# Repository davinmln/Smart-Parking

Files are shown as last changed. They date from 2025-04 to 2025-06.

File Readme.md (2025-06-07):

# 🛜 SMART PARKING
<p align="center">
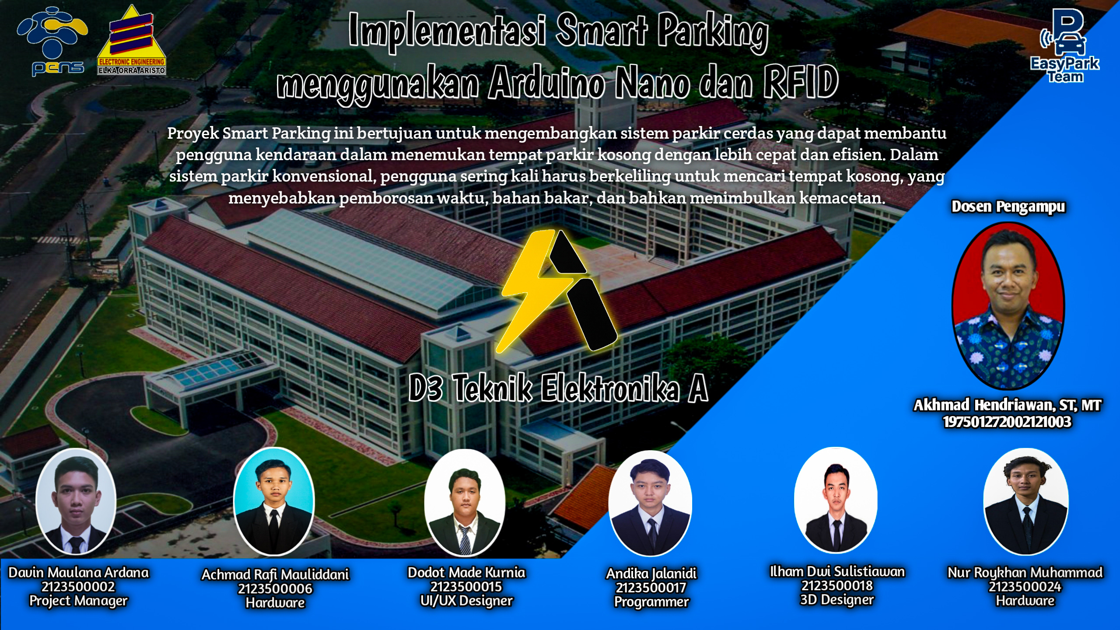
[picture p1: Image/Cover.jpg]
   
</p>

## Support By :
- Dosen Pengampu : Akhmad Hendriawan ST, MT
- Mata Kuliah : Workshop Mikrokontroller
- Program Studi : D3 Teknik Elektronika
- Institusi : Politeknik Elektronika Negeri Surabaya ( PENS )
  
## 👥 EasyPark Team Member
<p align="center">
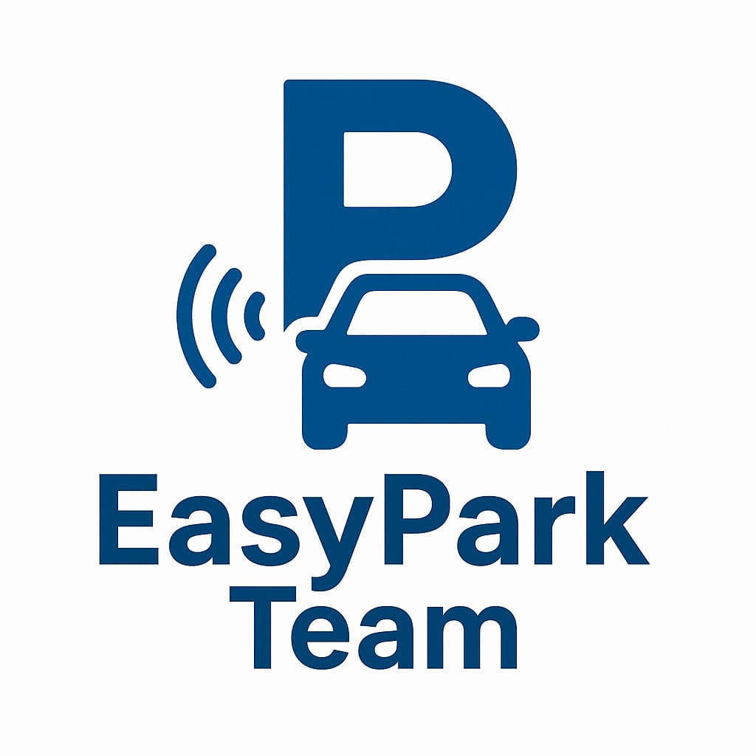
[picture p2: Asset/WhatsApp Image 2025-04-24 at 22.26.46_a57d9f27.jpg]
  
</p>

| Nama | Nrp | Jobdesk |
|:---:|:---:|:---:|
| Davin Maulana Ardana  | 2123500002 | Project Manager |
| Achmad Rafi Mauliddani  | 2123500006 | Hardware |
| Dodot Made Kurnia  | 2123500015 | UI/UX Designer |
| Andika Jalanidi  | 2123500017 | Programmer |
| Ilham Dwi Sulistiawan  | 2123500018 | 3D Designer |
| Nur Roykhan Muhammad | 2123500024 | Hardware |

## Deskripsi Projek
Sistem Smart Parking adalah solusi berbasis teknologi untuk mempermudah pencarian tempat parkir di area umum, seperti apartemen, pusat perbelanjaan, dan area publik lainnya. Sistem ini menggunakan sensor dan teknologi IoT untuk mendeteksi ketersediaan parkir secara real-time dan memberikan informasi langsung kepada pengguna. Tujuan utama proyek ini adalah untuk mengurangi waktu yang dihabiskan pengemudi dalam mencari tempat parkir dan mengoptimalkan penggunaan lahan parkir yang ada. Sistem ini tidak hanya memberikan kenyamanan bagi pengguna dengan cara yang efisien dan cepat, tetapi juga membantu pengelola parkir dalam memonitor kapasitas dan pendapatan parkir secara otomatis.

## Tujuan Proyek
- Menyediakan solusi parkir yang efisien dan modern untuk mengurangi waktu pencarian tempat parkir oleh pengguna.
- Mengurangi kemacetan di area parkir akibat kendaraan yang berkeliling mencari slot kosong.
- Memberikan informasi ketersediaan tempat parkir secara akurat kepada pengguna.
  
## Komponen 
| Nama Komponen | Kegunaan |
|:---:|:---:|
| Limit Swich | Untuk mengetahui di bagian mana slot parkir yang kosong |
| Infrared Sensor | Untuk mendeteksi apakah mobil sudah melewati pintu parkir |
| RFID  | Sebagai akses keluar dan masuk kendaraan | 
| Servo  | Untuk membuka dan menutup pintu masuk | 
| Arduino Uno  | Sebagai mikrokontroler yang akam di gunakan |
| Lcd Dislay 16x2 | Untuk menampilkan slot kosong di parkiran di pintu masuk |

## Blok Diagram Sistem
<p align="center">
   Foto Tim EasyPark
</p>

## Design PCB
<p align="center">
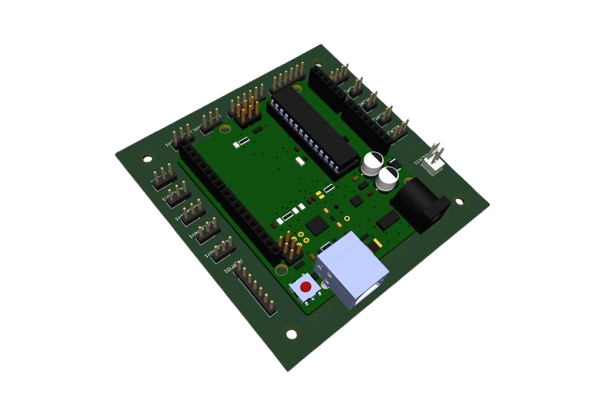
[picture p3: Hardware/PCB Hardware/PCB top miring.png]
   
</p>

## 3D Design Parking Slot
<p align="center">
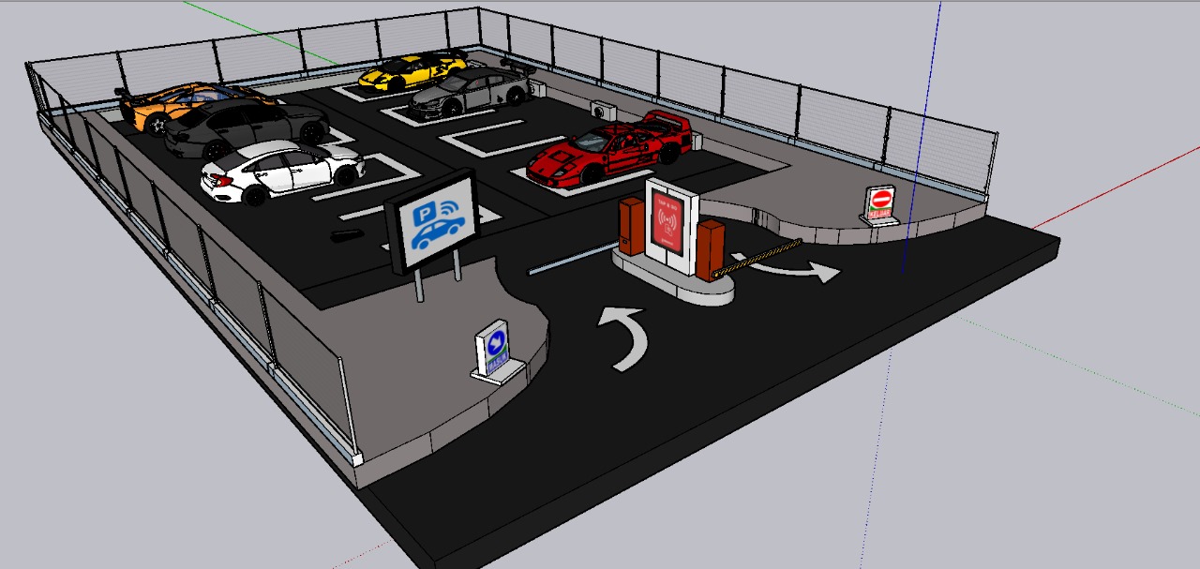
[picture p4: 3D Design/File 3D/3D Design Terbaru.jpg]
   
</p>

## Link Thingiverse 3D Design

**🔗[Teruskan ke website Thingverse](https://www.thingiverse.com/thing:7059087)**

## UI/UX Design
<p align="center">
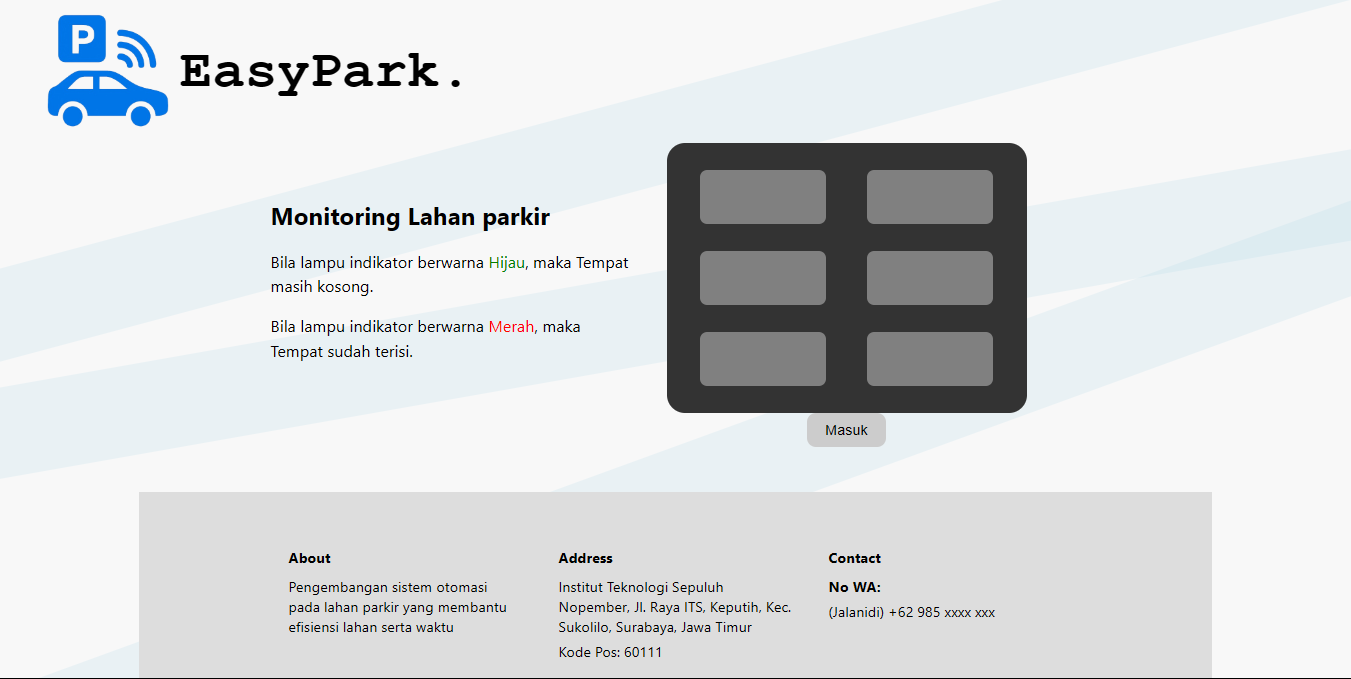
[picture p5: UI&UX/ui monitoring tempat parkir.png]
Foto ui EasyPark
  
</p>

## Simulasi Wokwi
<p align="center">
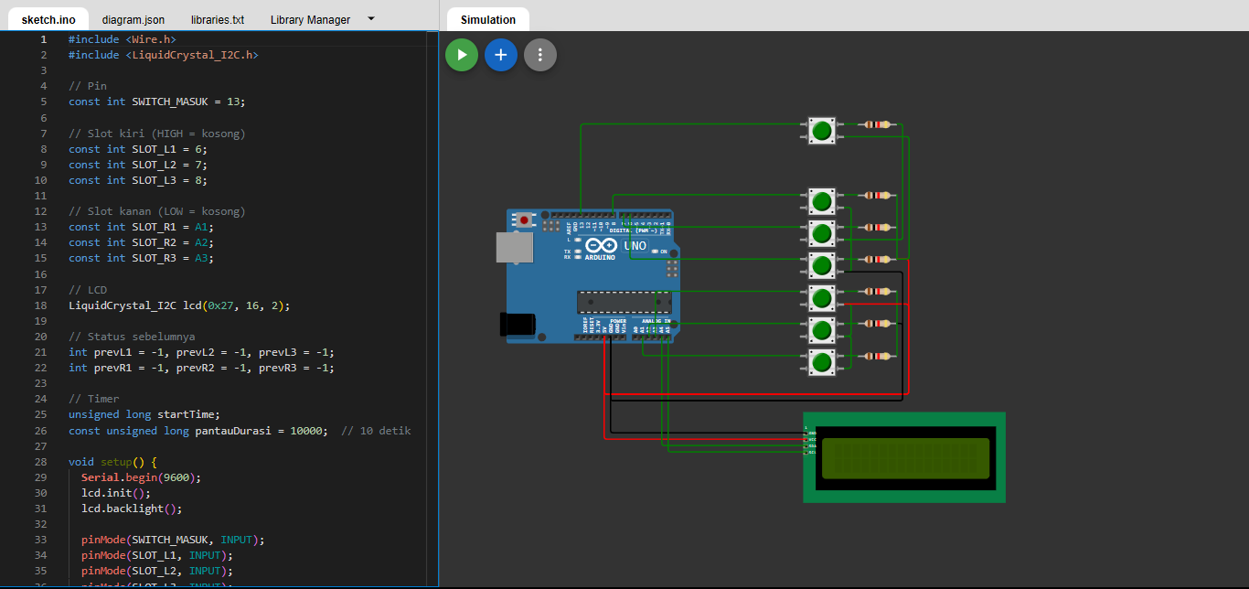
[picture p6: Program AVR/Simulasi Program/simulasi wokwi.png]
Foto simulasi wokwi
  
</p>

## Link Simulasi Wokwi
**🔗[Teruskan ke website Wokwi](https://wokwi.com/projects/433106752911339521)**

## Video Iklan
https://github.com/user-attachments/assets/c66144eb-d369-47d5-b7e9-3379c96ada36

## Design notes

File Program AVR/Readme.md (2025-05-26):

#include <SPI.h>
#include <MFRC522.h>
#include <Servo.h>
#include <Wire.h>
#include <LiquidCrystal_I2C.h>

// RFID
#define SS_PIN 9
#define RST_PIN 10
MFRC522 mfrc522(SS_PIN, RST_PIN);
byte allowedUID[4] = {0x73, 0xDF, 0x91, 0xE2}; // Ganti sesuai UID kartu Anda

// Servo
Servo servoMasuk;
Servo servoKeluar;
const int SERVO_MASUK_PIN = 3;
const int SERVO_KELUAR_PIN = 5;

// Sensor & tombol
const int SENSOR_IR_MASUK = 2;
const int SENSOR_IR_KELUAR = 4;
const int SWITCH_KELUAR = A0;

// Slot kiri (HIGH = kosong)
const int SLOT_L1 = 6;
const int SLOT_L2 = 7;
const int SLOT_L3 = 8;

// Slot kanan (LOW = kosong)
const int SLOT_R1 = A1;
const int SLOT_R2 = A2;
const int SLOT_R3 = A3;

// LCD
LiquidCrystal_I2C lcd(0x27, 16, 2);

// Timer kirim status slot
unsigned long lastSendTime = 0;
const unsigned long interval = 1000;  // 1 detik

// Variabel status slot sebelumnya
int prevL1 = -1, prevL2 = -1, prevL3 = -1;
int prevR1 = -1, prevR2 = -1, prevR3 = -1;

void setup() {
  Serial.begin(9600);
  SPI.begin();
  mfrc522.PCD_Init();

  lcd.init();
  lcd.backlight();
  tampilkanSiapScan();

  servoMasuk.attach(SERVO_MASUK_PIN);
  servoKeluar.attach(SERVO_KELUAR_PIN);
  servoMasuk.write(0);
  servoKeluar.write(0);

  pinMode(SENSOR_IR_MASUK, INPUT);
  pinMode(SENSOR_IR_KELUAR, INPUT);
  pinMode(SWITCH_KELUAR, INPUT);

  pinMode(SLOT_L1, INPUT);
  pinMode(SLOT_L2, INPUT);
  pinMode(SLOT_L3, INPUT);
  pinMode(SLOT_R1, INPUT);
  pinMode(SLOT_R2, INPUT);
  pinMode(SLOT_R3, INPUT);
}

void loop() {
  if (millis() - lastSendTime >= interval) {
    kirimStatusSlot();
    lastSendTime = millis();
  }

  // MODE KELUAR
  if (digitalRead(SWITCH_KELUAR) == LOW) {
    lcd.clear();
    lcd.setCursor(2, 0); lcd.print("Akses Keluar");
    lcd.setCursor(0, 1); lcd.print("Tab Access Card");

    while (digitalRead(SWITCH_KELUAR) == LOW) {
      if (millis() - lastSendTime >= interval) {
        kirimStatusSlot();
        lastSendTime = millis();
      }

      if (mfrc522.PICC_IsNewCardPresent() && mfrc522.PICC_ReadCardSerial()) {
        if (isAllowedUID(mfrc522.uid.uidByte)) {
          mfrc522.PICC_HaltA();
          tampilkanSelamatJalan();
          prosesKeluar();
          break;
        } else {
          lcd.clear();
          lcd.setCursor(3, 0); lcd.print("Kartu Tidak");
          lcd.setCursor(2, 1); lcd.print("Dikenal");
          delayLCD(1000);
          lcd.setCursor(2, 0); lcd.print("Akses Keluar");
          lcd.setCursor(0, 1); lcd.print("Tab Access Card");
        }
      }
    }

    if (digitalRead(SWITCH_KELUAR) == HIGH) {
      tampilkanSiapScan();
    }
    return;
  }

  // Mode masuk - hanya via RFID
  if (!mfrc522.PICC_IsNewCardPresent() || !mfrc522.PICC_ReadCardSerial()) return;

  if (isAllowedUID(mfrc522.uid.uidByte)) {
    bukaPintuMasuk();
    tampilkanSlotKosong();
    tungguKendaraanMasuk();
    tutupPintuMasuk();
  } else {
    lcd.clear();
    lcd.setCursor(0, 0); lcd.print("Akses Ditolak");
    lcd.setCursor(0, 1); lcd.print("Coba lagi");
    delayLCD(1000);
  }

  mfrc522.PICC_HaltA();
  tampilkanSiapScan();
}

// --- Fungsi Cek UID ---
bool isAllowedUID(byte *uid) {
  for (byte i = 0; i < 4; i++) {
    if (uid[i] != allowedUID[i]) return false;
  }
  return true;
}

// --- Tampilkan LCD ---
void tampilkanSiapScan() {
  lcd.clear();
  lcd.setCursor(1, 0); lcd.print("SMART PARKING");
  lcd.setCursor(0, 1); lcd.print("Tab Access Card");
}

void tampilkanSlotKosong() {
  bool L1 = digitalRead(SLOT_L1) == HIGH;
  bool L2 = digitalRead(SLOT_L2) == HIGH;
  bool L3 = digitalRead(SLOT_L3) == HIGH;
  bool R1 = digitalRead(SLOT_R1) == LOW;
  bool R2 = digitalRead(SLOT_R2) == LOW;
  bool R3 = digitalRead(SLOT_R3) == LOW;

  lcd.clear();
  lcd.setCursor(2, 0);
  lcd.print("L:");
  lcd.print(R1 ? "1" : "X");
  lcd.print(R2 ? "2" : "X");
  lcd.print(R3 ? "3" : "X");
  lcd.print(" R:");
  lcd.print(L1 ? "1" : "X");
  lcd.print(L2 ? "2" : "X");
  lcd.print(L3 ? "3" : "X");

  lcd.setCursor(1, 1); lcd.print("Silakan Masuk");
  delayLCD(1000);
}

void tampilkanSelamatJalan() {
  lcd.clear();
  lcd.setCursor(1, 0); lcd.print("Selamat Jalan");
  lcd.setCursor(3, 1); lcd.print("Hati-hati");
  delayLCD(1000);
}

// --- Kontrol Pintu ---
void bukaPintuMasuk() {
  servoMasuk.write(90);
}
void tutupPintuMasuk() {
  servoMasuk.write(0);
}
void tungguKendaraanMasuk() {
  while (digitalRead(SENSOR_IR_MASUK) == HIGH) {
    delay(10);
    kirimStatusSlot();
  }
  lcd.setCursor(0, 1); lcd.print("Kendaraan Masuk");
  while (digitalRead(SENSOR_IR_MASUK) == LOW) {
    delay(10);
    kirimStatusSlot();
  }
}

void prosesKeluar() {
  bukaPintuKeluar();
  tungguKendaraanKeluar();
  tutupPintuKeluar();
  tampilkanSiapScan();
}
void bukaPintuKeluar() {
  servoKeluar.write(90);
}
void tutupPintuKeluar() {
  servoKeluar.write(0);
}
void tungguKendaraanKeluar() {
  while (digitalRead(SENSOR_IR_KELUAR) == HIGH) {
    delay(10);
    kirimStatusSlot();
  }
  lcd.setCursor(0, 1); lcd.print("Kendaraan Keluar");
  while (digitalRead(SENSOR_IR_KELUAR) == LOW) {
    delay(10);
    kirimStatusSlot();
  }
}

// --- Delay non-blokir untuk LCD + Serial ---
void delayLCD(unsigned long durasi) {
  unsigned long start = millis();
  while (millis() - start < durasi) {
    if (millis() - lastSendTime >= interval) {
      kirimStatusSlot();
      lastSendTime = millis();
    }
  }
}

// --- Kirim Status Slot ke Serial dalam Format JSON ---
void kirimStatusSlot() {
  int L1 = digitalRead(SLOT_L1) == LOW ? 1 : 0;
  int L2 = digitalRead(SLOT_L2) == LOW ? 1 : 0;
  int L3 = digitalRead(SLOT_L3) == LOW ? 1 : 0;
  int R1 = digitalRead(SLOT_R1) != LOW;
  int R2 = digitalRead(SLOT_R2) != LOW;
  int R3 = digitalRead(SLOT_R3) != LOW;

  // Kirim hanya jika berubah atau dipanggil periodik
  if (L1 != prevL1 || L2 != prevL2 || L3 != prevL3 ||
      R1 != prevR1 || R2 != prevR2 || R3 != prevR3) {

    Serial.print("{\"L1\":"); Serial.print(L1);
    Serial.print(",\"L2\":"); Serial.print(L2);
    Serial.print(",\"L3\":"); Serial.print(L3);
    Serial.print(",\"R1\":"); Serial.print(R1);
    Serial.print(",\"R2\":"); Serial.print(R2);
    Serial.print(",\"R3\":"); Serial.print(R3);
    Serial.println("}");

    prevL1 = L1; prevL2 = L2; prevL3 = L3;
    prevR1 = R1; prevR2 = R2; prevR3 = R3;
  }
}

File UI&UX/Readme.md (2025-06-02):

# *Tampilan design UI monitoring tempat parkir*

<p align="center">
  Foto ui EasyPark
</p>

# *Tampilan design UI Pada Figma*
<p align="center">
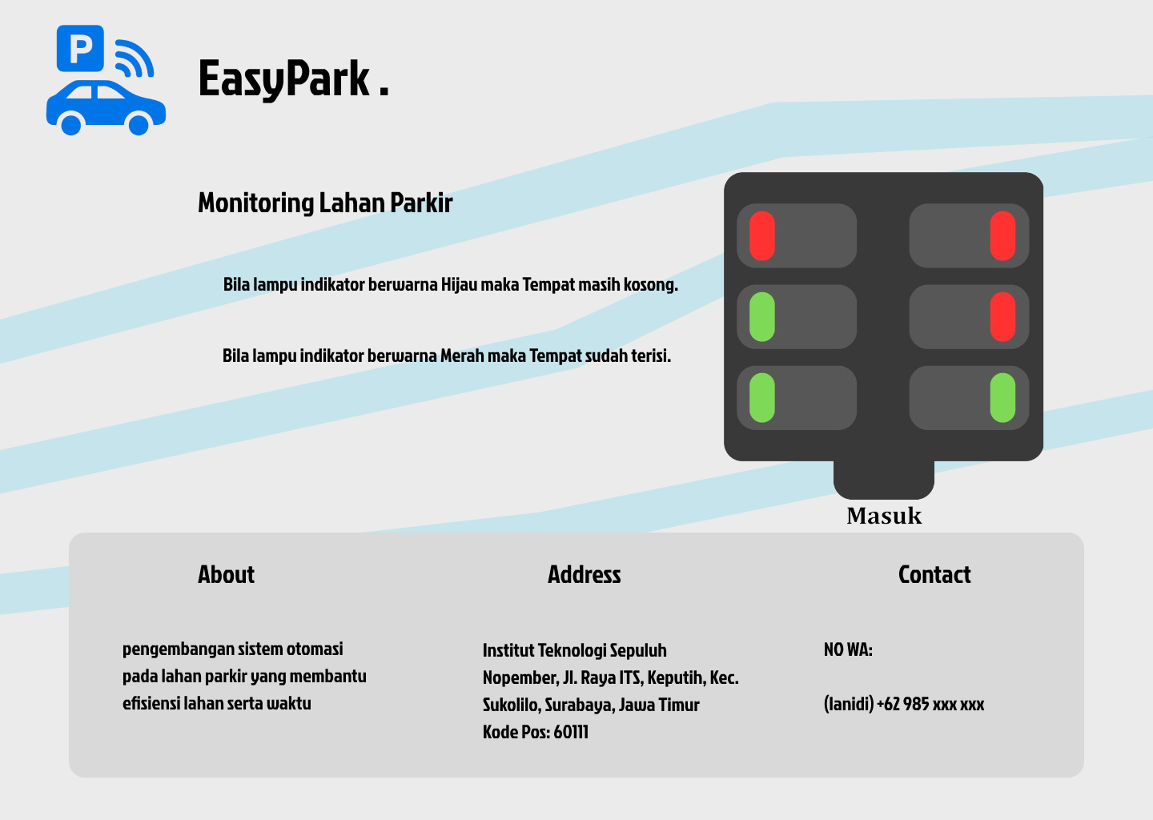
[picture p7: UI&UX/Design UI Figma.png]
Foto Figma EasyPark
  
</p>

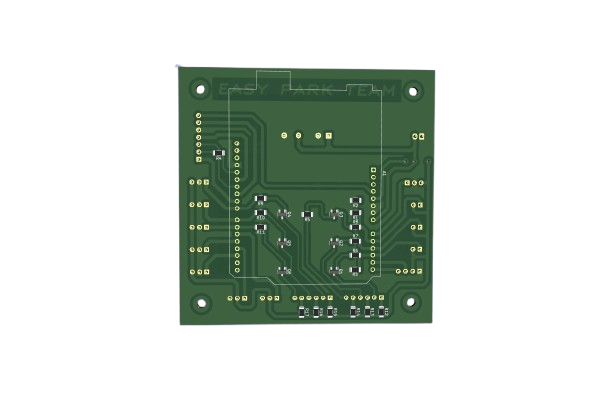
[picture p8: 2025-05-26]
Hardware/PCB Hardware/PCB buttom.png

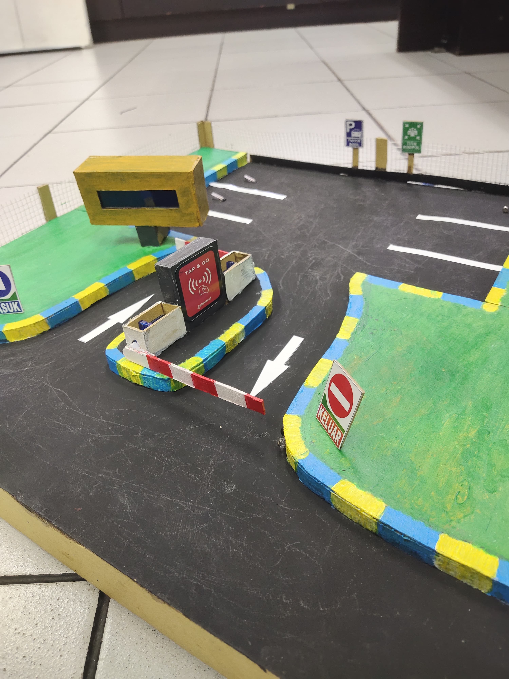
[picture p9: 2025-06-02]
3D Design/File 3D/3D Jadi 2.jpg

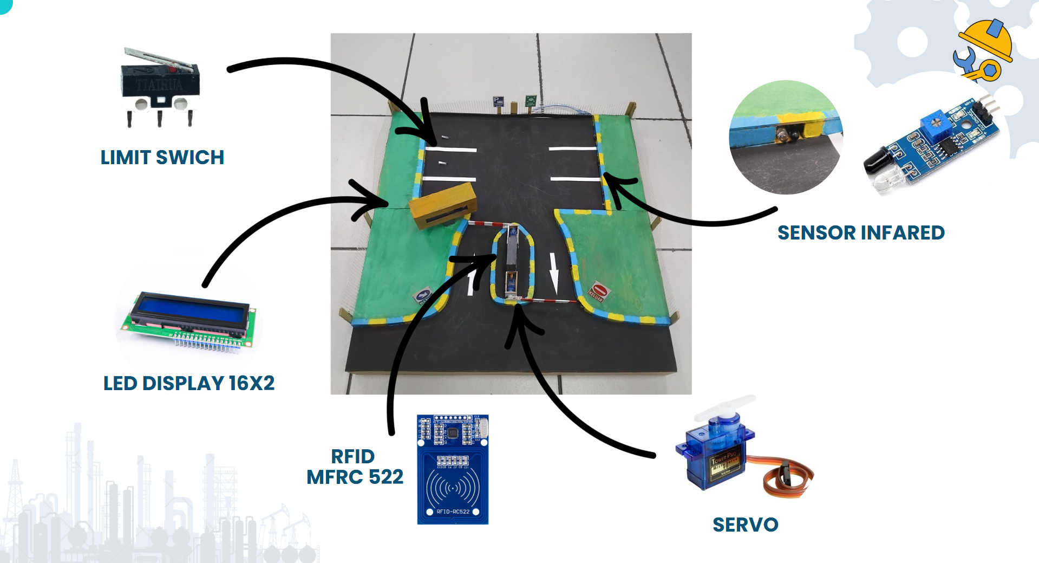
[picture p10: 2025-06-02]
3D Design/Foto Mekanik/Foto Mekanik.png

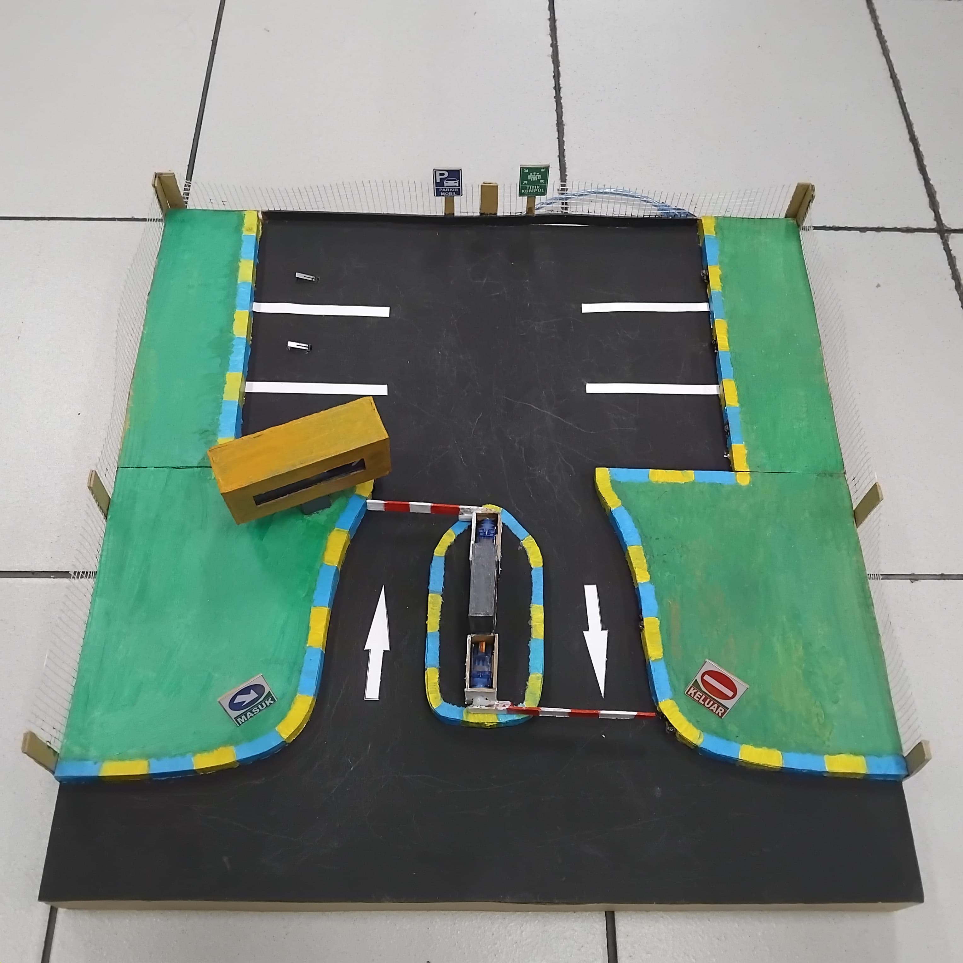
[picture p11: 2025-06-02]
3D Design/File 3D/3D Jadi 1.jpg

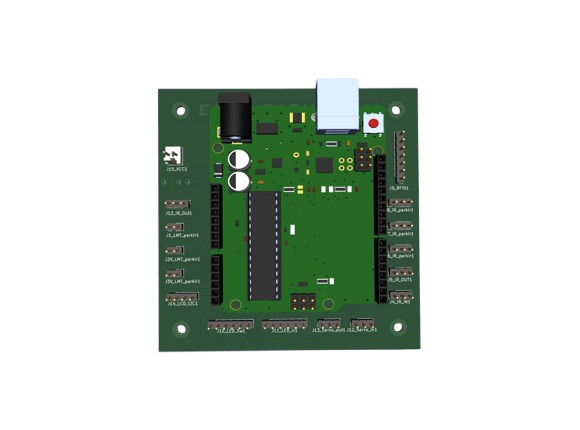
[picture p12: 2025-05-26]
Hardware/PCB Hardware/PCB top.png

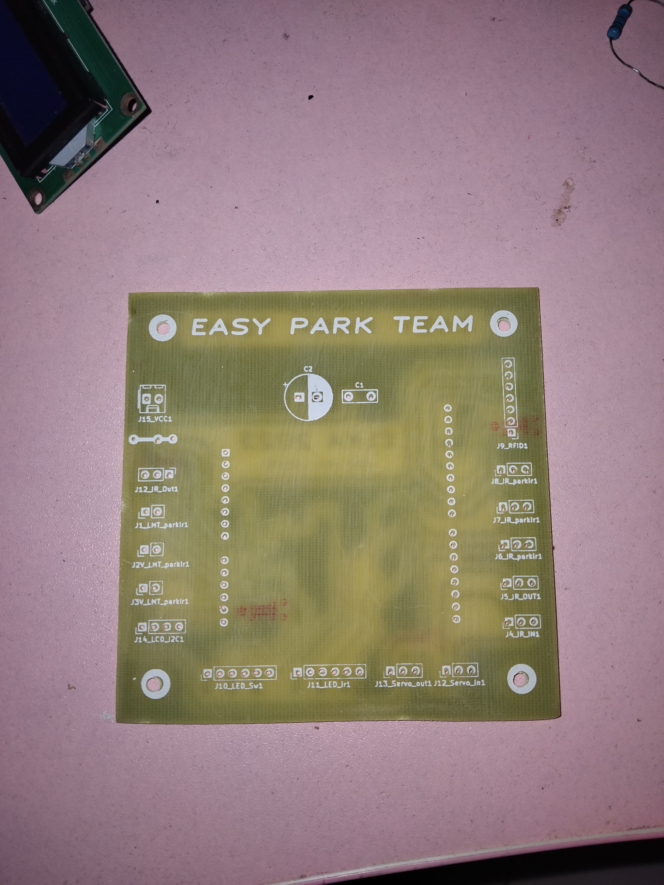
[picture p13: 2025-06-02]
Hardware/PCB Hardware/pcb jadi.jpg

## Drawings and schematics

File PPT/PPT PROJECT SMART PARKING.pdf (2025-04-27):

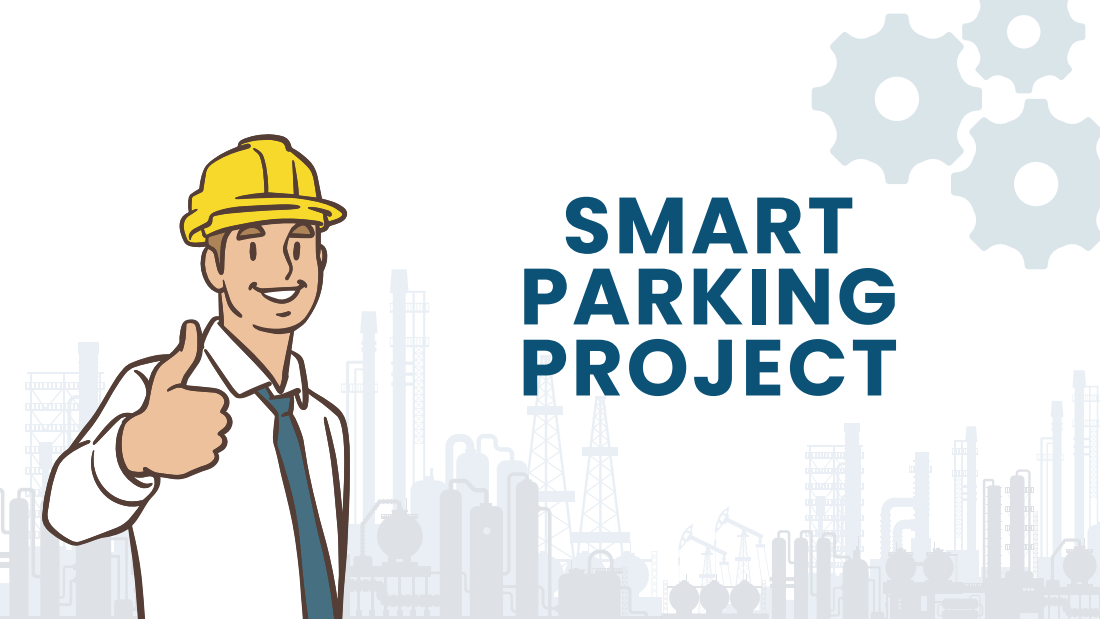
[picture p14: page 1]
SMART PARKING PROJECT

# MEMBER

02

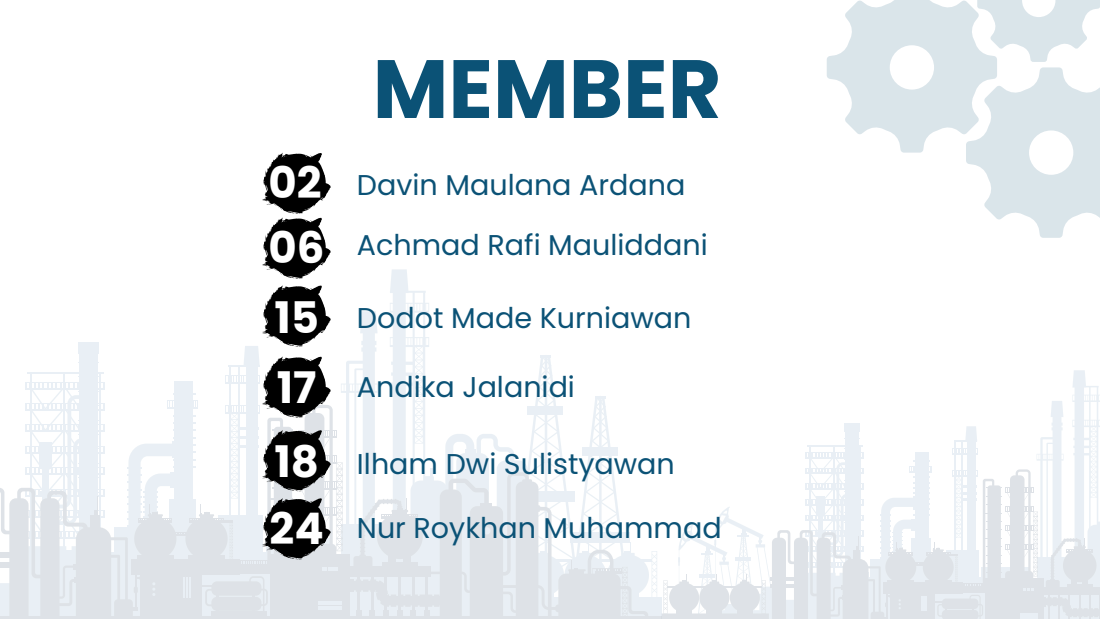
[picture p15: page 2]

Davin Maulana Ardana
Achmad Rafi Mauliddani
Dodot Made Kurniawan
Andika Jalanidi
Ilham Dwi Sulistyawan
Nur Roykhan Muhammad

## Saat ini sistem parkir di indonesia

# LATAR

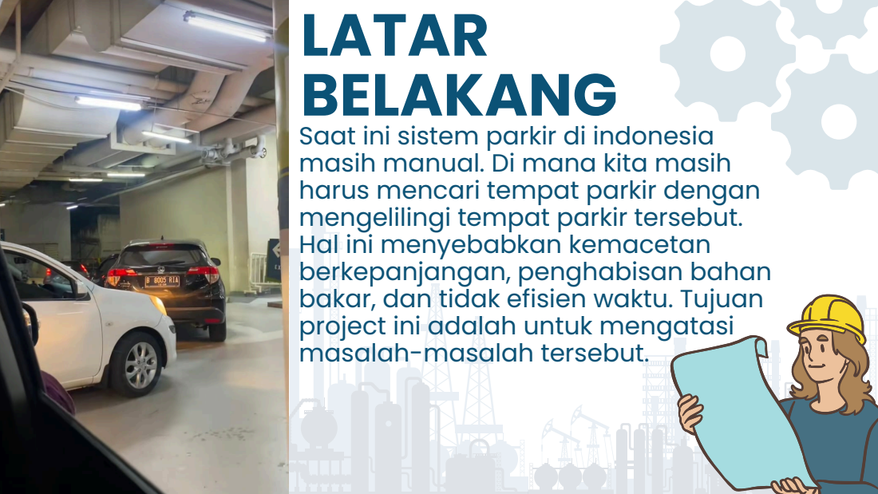
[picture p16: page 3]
BELAKANG

masih manual. Di mana kita masih
harus mencari tempat parkir dengan
mengelilingi tempat parkir tersebut.
Hal ini menyebabkan kemacetan
berkepanjangan, penghabisan bahan
bakar, dan tidak efisien waktu. Tujuan
project ini adalah untuk mengatasi
masalah-masalah tersebut.

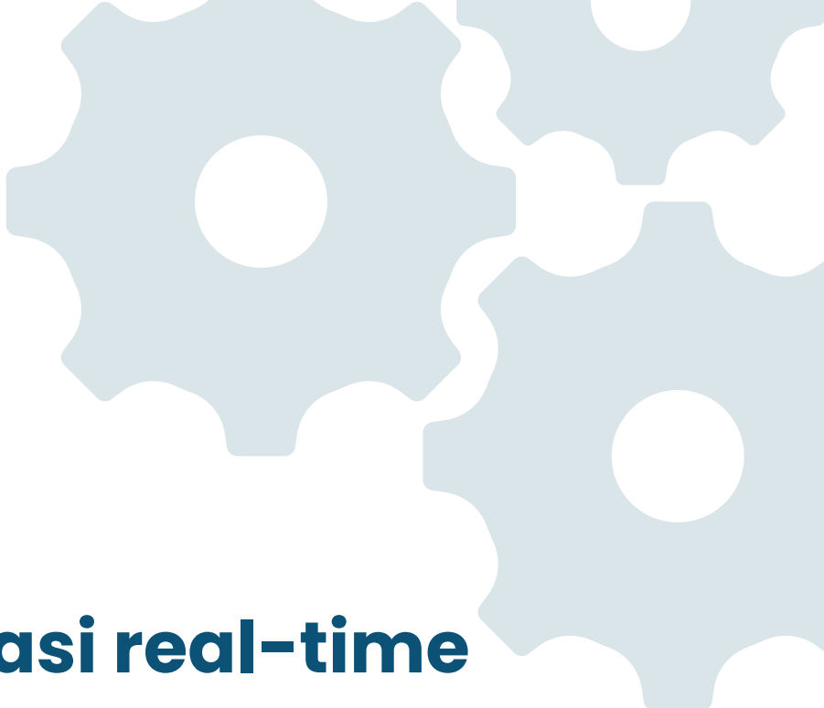
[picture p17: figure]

### Bagaimana cara sistem Smart Parking memberikan informasi real-time tentang ketersediaan tempat parkir kepada pengendara? Apa dampak penerapan teknologi Smart Parking terhadap efisiensi waktu

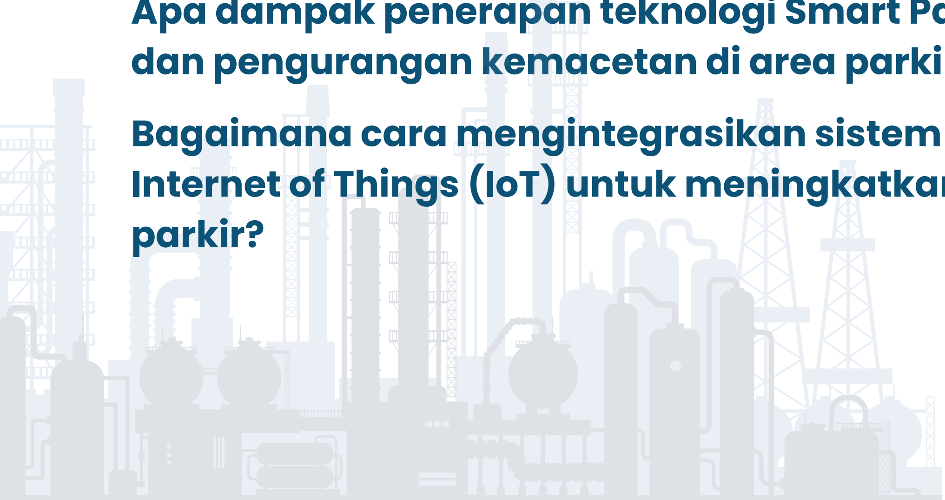
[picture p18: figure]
parkir?

### dan pengurangan kemacetan di area parkir yang sering penuh?

# RUMUSAN MASALAH

### Bagaimana cara mengintegrasikan sistem Smart Parking dengan teknologi

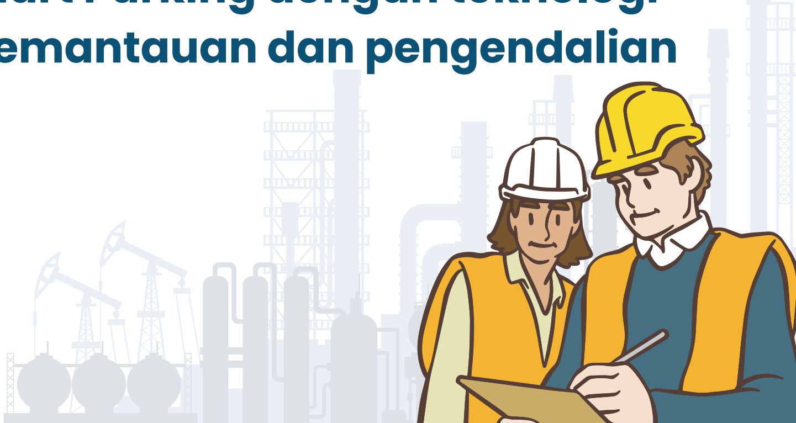
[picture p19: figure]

### Internet of Things (IoT) untuk meningkatkan pemantauan dan pengendalian

# TUJUAN PENELITIAN

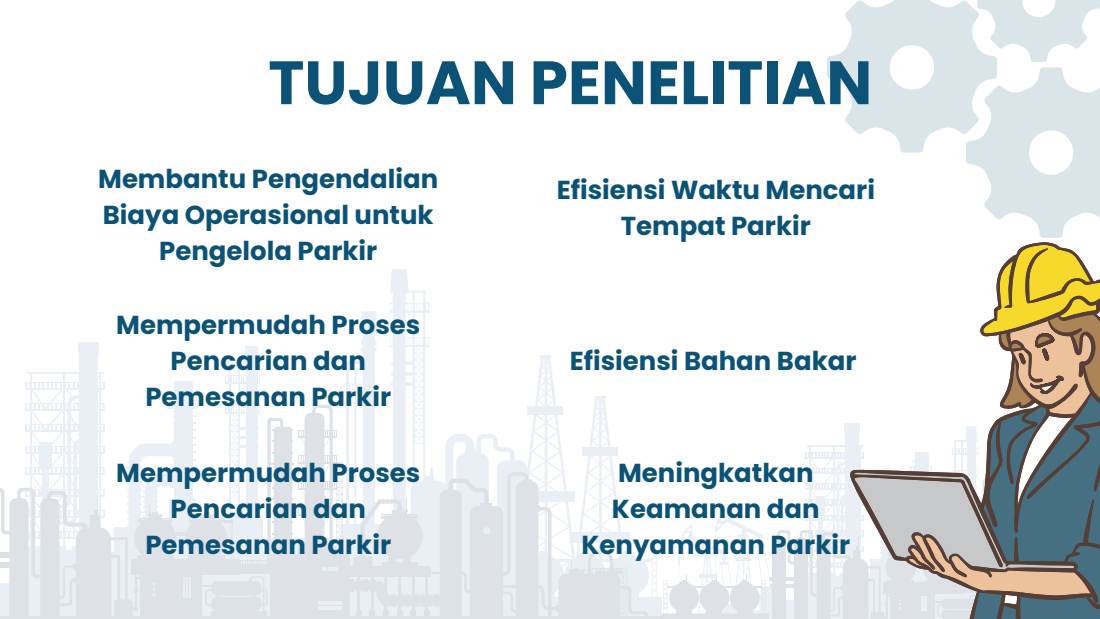
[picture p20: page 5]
Mempermudah Proses Pencarian dan Pemesanan Parkir; Meningkatkan Keamanan dan Kenyamanan Parkir

Membantu Pengendalian
Biaya Operasional untuk
Pengelola Parkir

Efisiensi Waktu Mencari
Tempat Parkir

Efisiensi Bahan Bakar

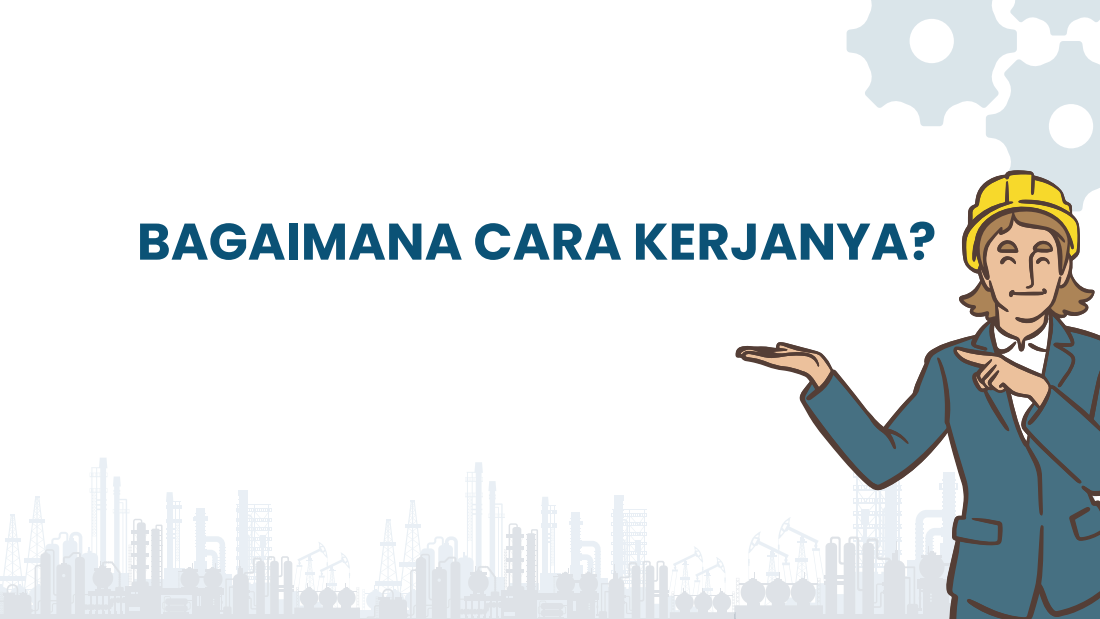
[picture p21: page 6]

BAGAIMANA CARA KERJANYA?

# BLOK DIAGRAM

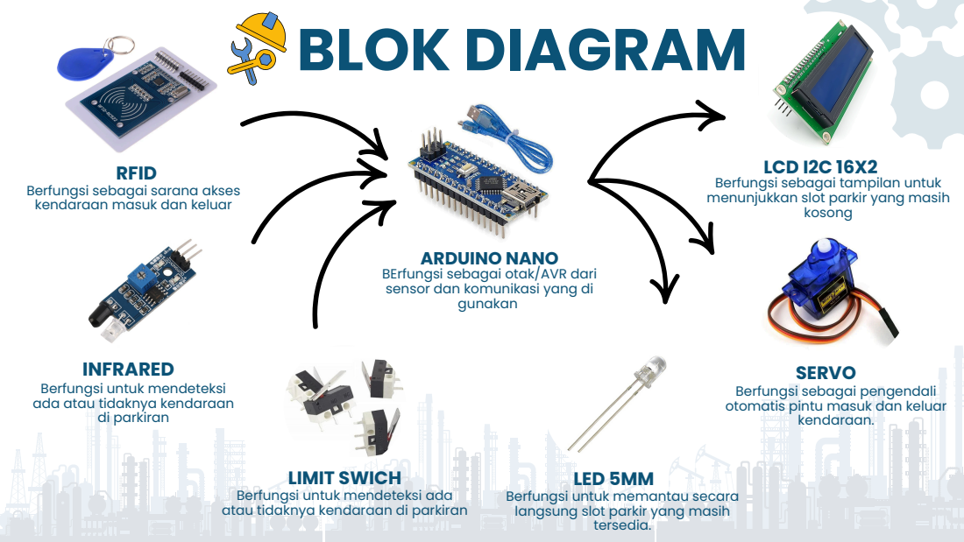
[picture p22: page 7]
gunakan; kosong; RFID; kendaraan.; SERVO; di parkiran; tersedia.; LED 5MM

LCD I2C 16X2
Berfungsi sebagai tampilan untuk
menunjukkan slot parkir yang masih

Berfungsi sebagai sarana akses
kendaraan masuk dan keluar

ARDUINO NANO
BErfungsi sebagai otak/AVR dari
sensor dan komunikasi yang di

INFRARED
Berfungsi untuk mendeteksi
ada atau tidaknya kendaraan

Berfungsi sebagai pengendali
otomatis pintu masuk dan keluar

LIMIT SWICH
Berfungsi untuk mendeteksi ada
atau tidaknya kendaraan di parkiran

Berfungsi untuk memantau secara
langsung slot parkir yang masih

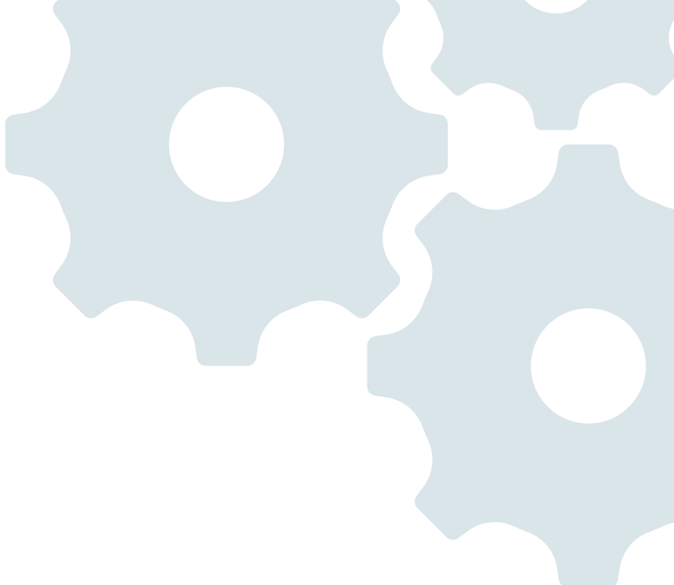
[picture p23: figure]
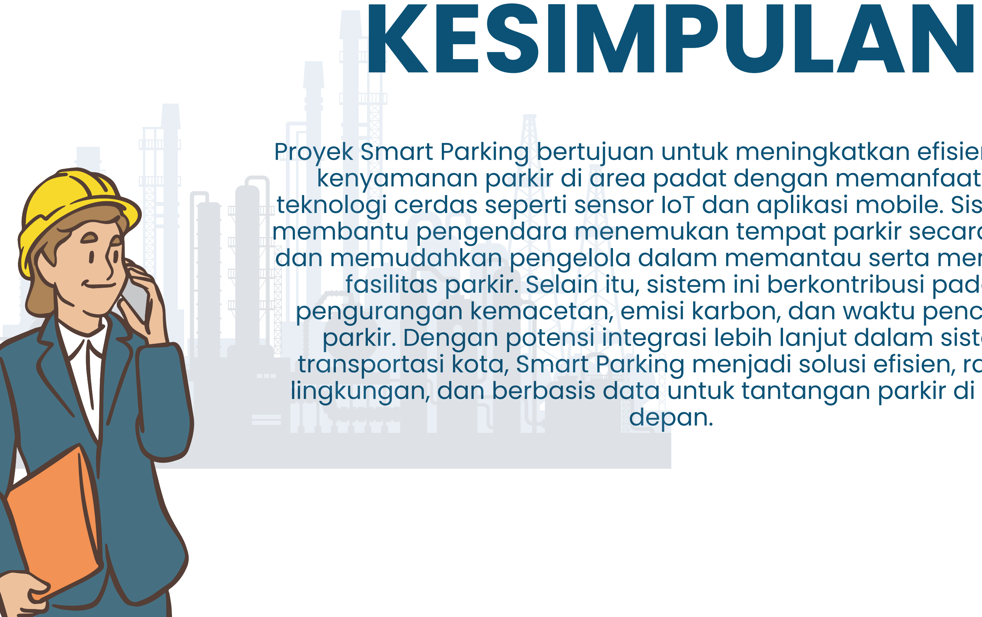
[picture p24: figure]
depan.; KESIMPULAN

Proyek Smart Parking bertujuan untuk meningkatkan efisiensi dan kenyamanan parkir di area padat dengan memanfaatkan teknologi cerdas seperti sensor IoT dan aplikasi mobile. Sistem ini membantu pengendara menemukan tempat parkir secara cepat dan memudahkan pengelola dalam memantau serta mengelola fasilitas parkir. Selain itu, sistem ini berkontribusi pada pengurangan kemacetan, emisi karbon, dan waktu pencarian parkir. Dengan potensi integrasi lebih lanjut dalam sistem transportasi kota, Smart Parking menjadi solusi efisien, ramah lingkungan, dan berbasis data untuk tantangan parkir di masa

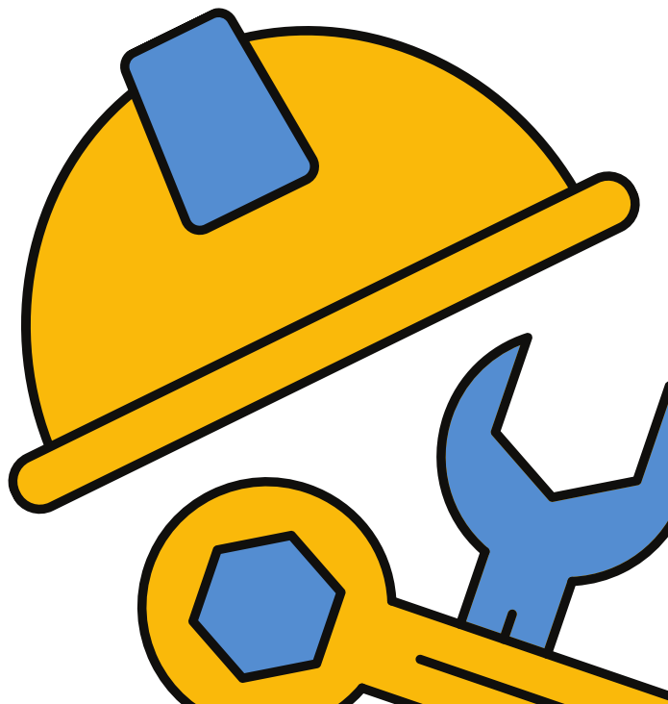
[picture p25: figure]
TERIMA KASIH




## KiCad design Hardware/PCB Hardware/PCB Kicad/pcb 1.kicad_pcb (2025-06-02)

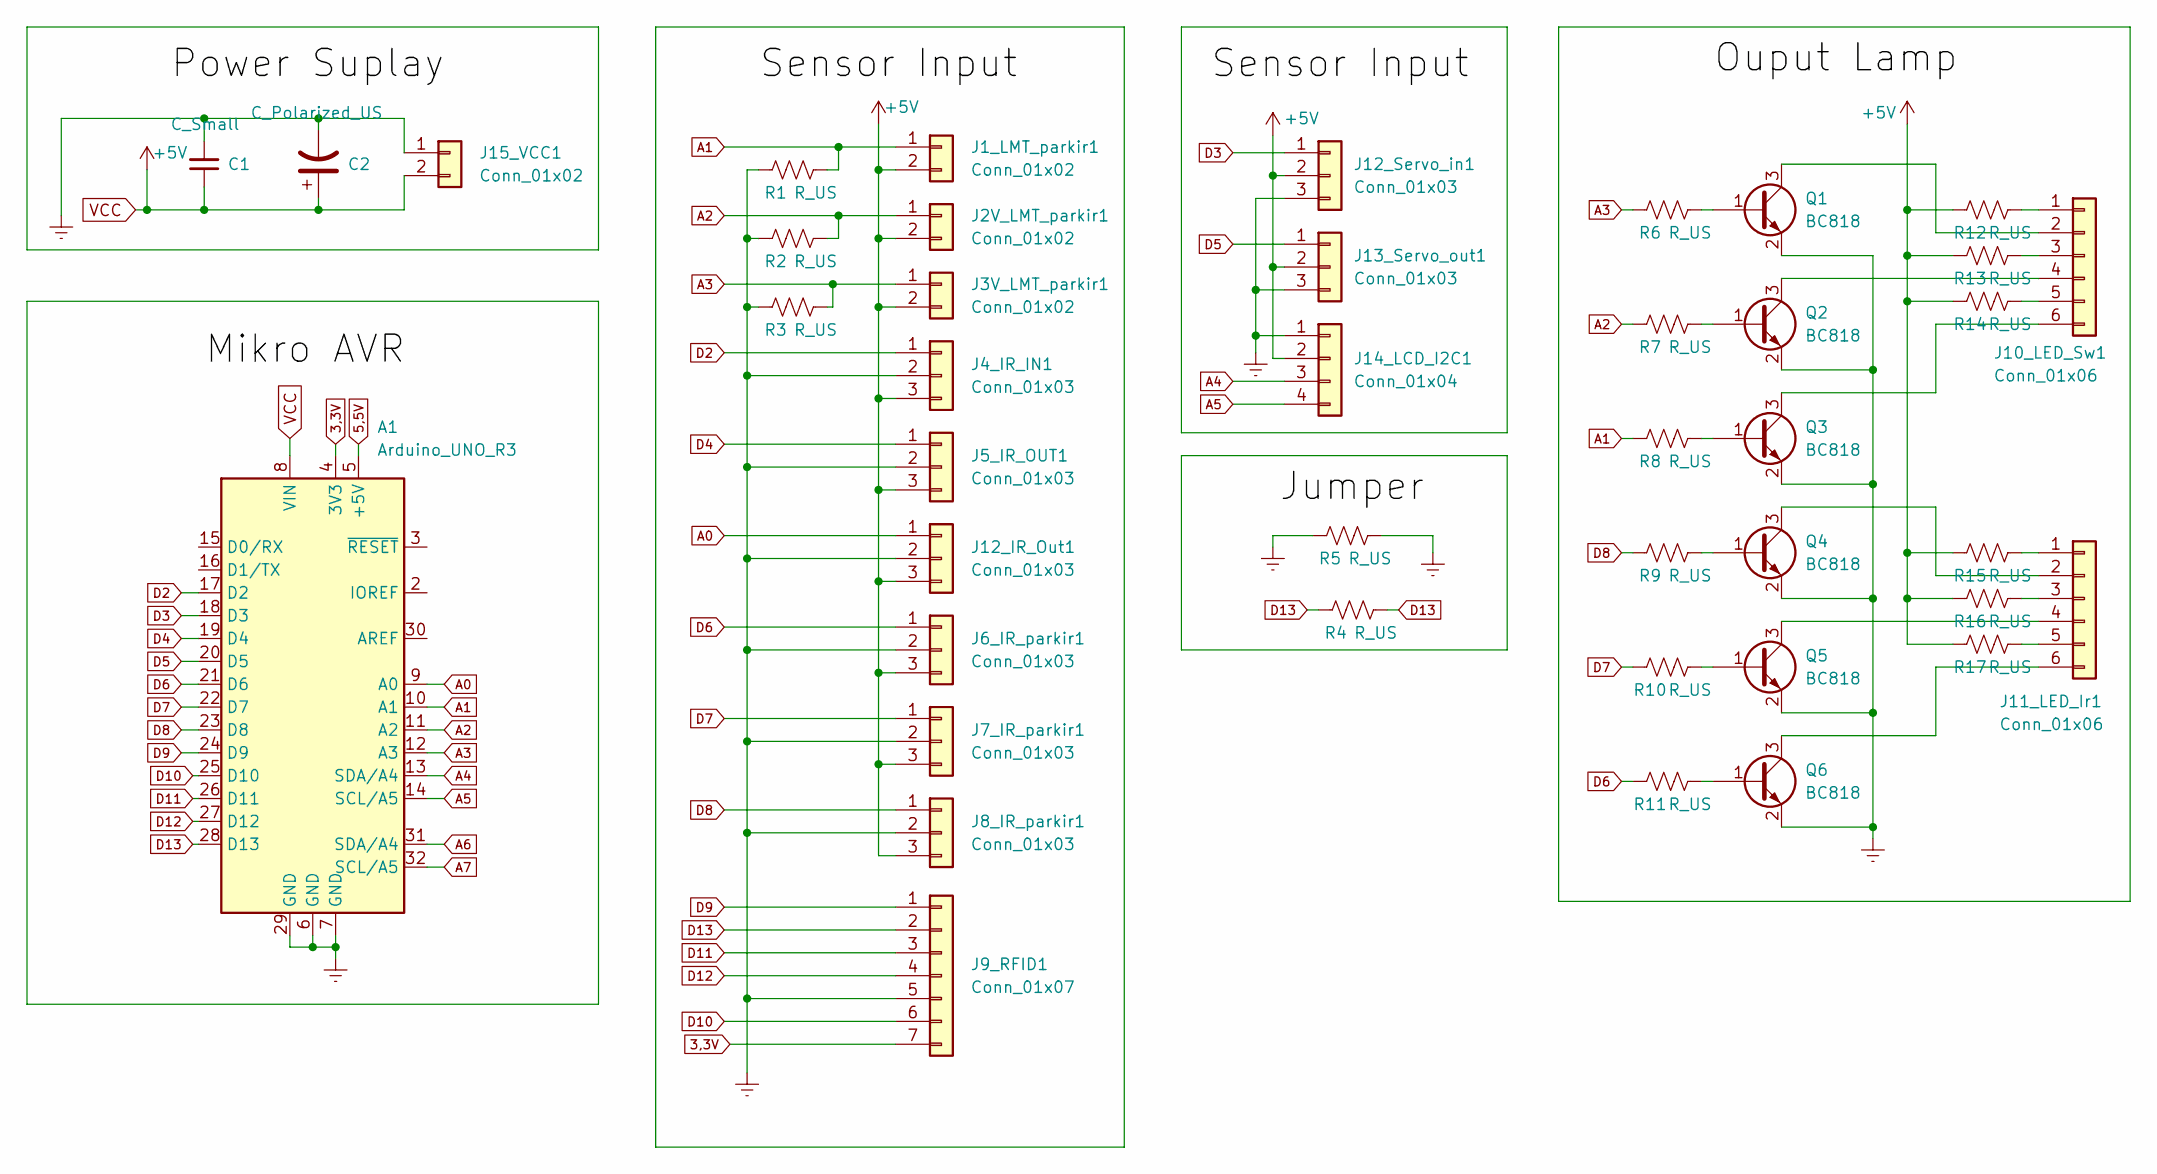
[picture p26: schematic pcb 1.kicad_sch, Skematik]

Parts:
A1: Arduino_UNO_R3
C1: C_Small; C_Disc_D7.5mm_W2.5mm_P5.00mm
C2: C_Polarized_US; CP_Radial_D10.0mm_P3.80mm
J1_LMT_parkir1, J2V_LMT_parkir1, J3V_LMT_parkir1: Conn_01x02; PinHeader_1x02_P2.54mm_Vertical
J4_IR_IN1, J5_IR_OUT1, J6_IR_parkir1, J7_IR_parkir1, J8_IR_parkir1, J12_IR_Out1, J12_Servo_in1, J13_Servo_out1: Conn_01x03; PinHeader_1x03_P2.54mm_Vertical
J9_RFID1: Conn_01x07; PinHeader_1x07_P2.54mm_Vertical
J10_LED_Sw1, J11_LED_Ir1: Conn_01x06; PinHeader_1x06_P2.54mm_Vertical
J14_LCD_I2C1: Conn_01x04; PinHeader_1x04_P2.54mm_Vertical
J15_VCC1: Conn_01x02; Molex_KK-254_AE-6410-02A_1x02_P2.54mm_Vertical
Q1, Q2, Q3, Q4, Q5, Q6: BC818; SOT-23
R1, R2, R3, R4, R5, R6, R7, R8, R9, R10, R11, R12, R13, R14, R15, R16, R17: R_US; R_1206_3216Metric

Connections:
3,3V: A1.4 (3V3), J9_RFID1.7
5,5V: A1.5 (+5V)
A0: A1.9 (A0), J12_IR_Out1.1
A1: A1.10 (A1), J1_LMT_parkir1.1, R1.1, R8.2
A2: A1.11 (A2), J2V_LMT_parkir1.1, R2.1, R7.2
A3: A1.12 (A3), J3V_LMT_parkir1.1, R3.1, R6.2
A4: A1.13 (SDA/A4), J14_LCD_I2C1.3
A5: A1.14 (SCL/A5), J14_LCD_I2C1.4
A6: A1.31 (SDA/A4)
A7: A1.32 (SCL/A5)
D2: A1.17 (D2), J4_IR_IN1.1
D3: A1.18 (D3), J12_Servo_in1.1
D4: A1.19 (D4), J5_IR_OUT1.1
D5: A1.20 (D5), J13_Servo_out1.1
D6: A1.21 (D6), J6_IR_parkir1.1, R11.2
D7: A1.22 (D7), J7_IR_parkir1.1, R10.2
D8: A1.23 (D8), J8_IR_parkir1.1, R9.2
D9: A1.24 (D9), J9_RFID1.1
D10: A1.25 (D10), J9_RFID1.6
D11: A1.26 (D11), J9_RFID1.3
D12: A1.27 (D12), J9_RFID1.4
D13: A1.28 (D13), J9_RFID1.2, R4.1, R4.2
Earth: A1.6 (GND), A1.7 (GND), A1.29 (GND), C1.2, C2.2, J4_IR_IN1.2, J5_IR_OUT1.2, J6_IR_parkir1.2, J7_IR_parkir1.2, J8_IR_parkir1.2, J9_RFID1.5, J12_IR_Out1.2, J12_Servo_in1.3, J13_Servo_out1.3, J14_LCD_I2C1.1, J15_VCC1.1, Q1.2 (E), Q2.2 (E), Q3.2 (E), Q4.2 (E), Q5.2 (E), Q6.2 (E), R1.2, R2.2, R3.2, R5.1, R5.2
unnamed: J10_LED_Sw1.1, R12.1
unnamed: J10_LED_Sw1.2, Q1.3 (C)
unnamed: J10_LED_Sw1.3, R13.1
unnamed: J10_LED_Sw1.4, Q2.3 (C)
unnamed: J10_LED_Sw1.5, R14.1
unnamed: J10_LED_Sw1.6, Q3.3 (C)
unnamed: J11_LED_Ir1.1, R15.1
unnamed: J11_LED_Ir1.2, Q4.3 (C)
unnamed: J11_LED_Ir1.3, R16.1
unnamed: J11_LED_Ir1.4, Q5.3 (C)
unnamed: J11_LED_Ir1.5, R17.1
unnamed: J11_LED_Ir1.6, Q6.3 (C)
unnamed: Q1.1 (B), R6.1
unnamed: Q2.1 (B), R7.1
unnamed: Q3.1 (B), R8.1
unnamed: Q4.1 (B), R9.1
unnamed: Q5.1 (B), R10.1
unnamed: Q6.1 (B), R11.1
VCC: A1.8 (VIN), C1.1, C2.1, J1_LMT_parkir1.2, J2V_LMT_parkir1.2, J3V_LMT_parkir1.2, J4_IR_IN1.3, J5_IR_OUT1.3, J6_IR_parkir1.3, J7_IR_parkir1.3, J8_IR_parkir1.3, J12_IR_Out1.3, J12_Servo_in1.2, J13_Servo_out1.2, J14_LCD_I2C1.2, J15_VCC1.2, R12.2, R13.2, R14.2, R15.2, R16.2, R17.2

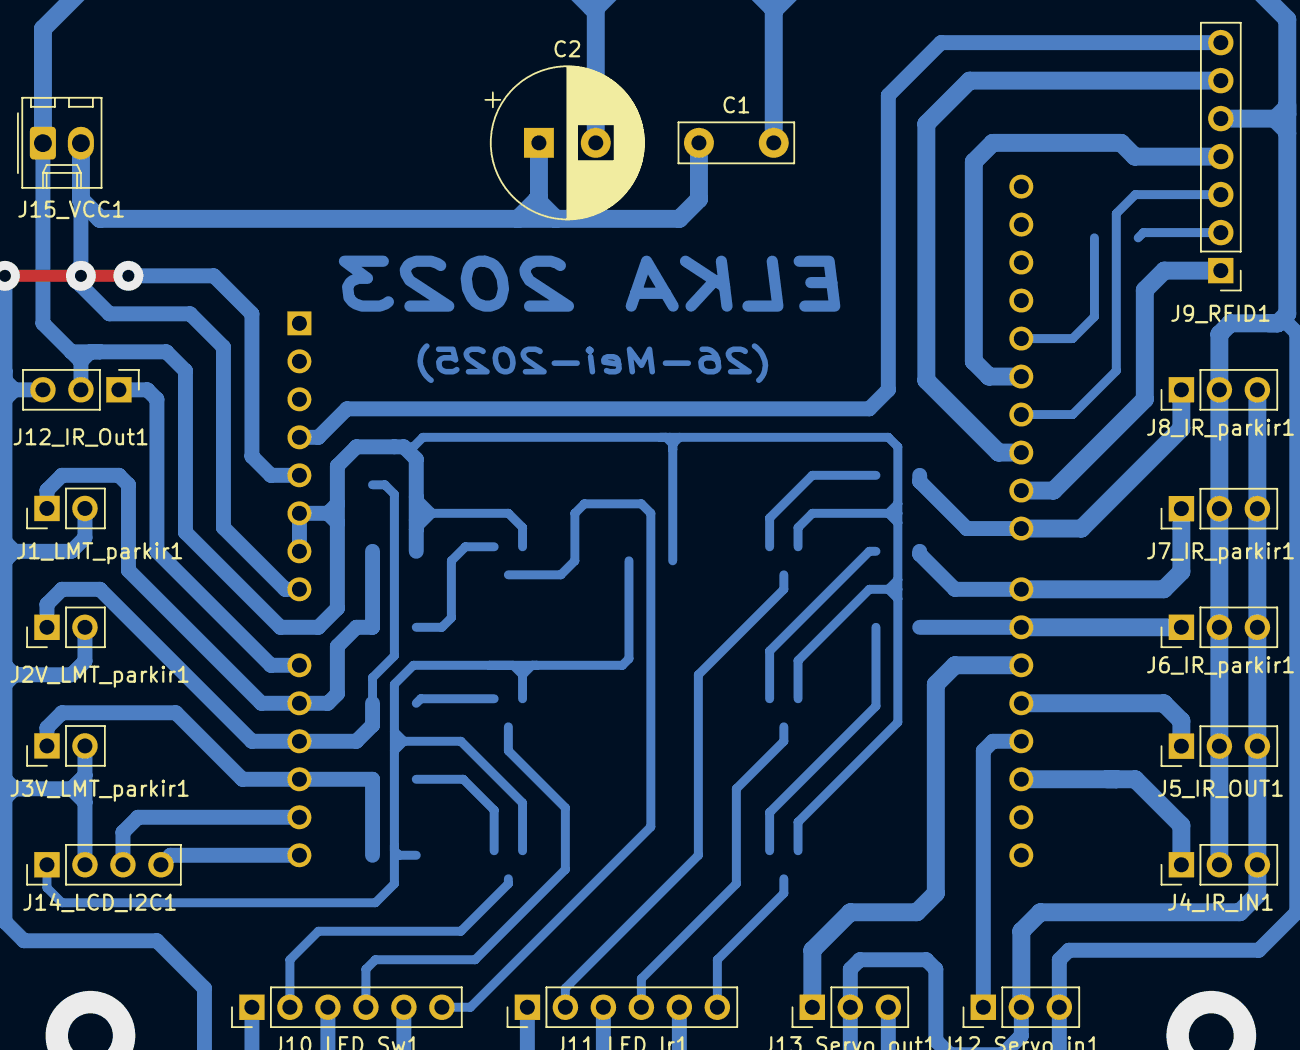
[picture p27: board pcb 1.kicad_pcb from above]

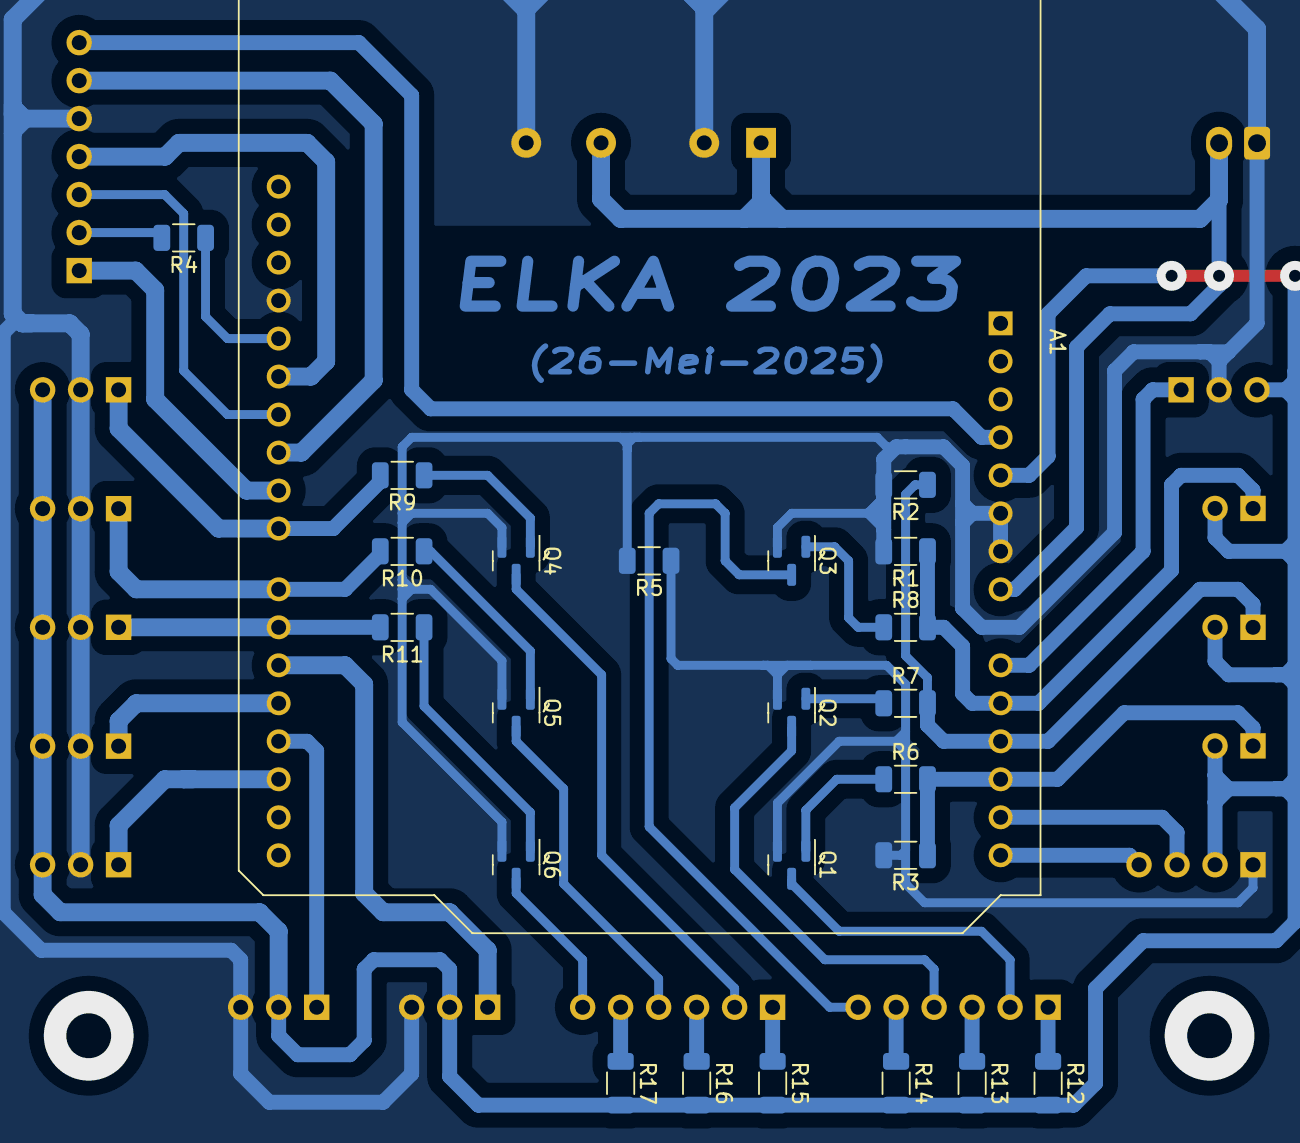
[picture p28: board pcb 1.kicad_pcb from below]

Board: 2 copper layers, 42 parts (24 on the bottom side), 39 nets.

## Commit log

2025-04-28 Create PCB
2025-06-02 Create PCB Kicad
